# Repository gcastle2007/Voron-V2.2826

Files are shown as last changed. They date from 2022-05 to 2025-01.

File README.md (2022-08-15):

## Configuration of Voron 2.2826

В данном репозитории находится мой актуальный конфиг от 3D принетра Voron 2.4 (V2.2826).

Даный конфиг написан полностью самостоятельно с нуля.
Какие-то дополнительные фичи из макросов были подсмотрены в конфигах нижепредставленных товарищей, разобраны для понимания и перепилены под себя:
- Zellner Alex (очень лютый конфиг, не для слабонервных): https://github.com/zellneralex/klipper_config
- ZZToP: https://github.com/zztopper/voron_v2.4_1030
- Vassssko: https://github.com/Vassssko/voron_v2.4_982

[Раздел макросов ](./MACROS/)

Запуск печати осуществляется через
```
PRINT_START EXTRUDER_TEMP=[first_layer_temperature] BED_TEMP=[first_layer_bed_temperature] CHAMBER=[chamber_temperature] FILAMENT=[filament_type] BMESH=True

Где:
    [first_layer_temperatire] - температура печати первого слоя
    [first_layer_bed_temperature] - температура стола для печати первого слоя
    [chamber_temperature] - минимальная необходима температура камеры для начала печати (сейчас не использую)
    [filament_type] - тип филамента используемого при печати. В зависимости от этого включается Nevermore и вытяжной вентилятор
    BMESH=True - сообщение принтеру, что нужно будет собрать Bed Mesh. Если не нужно, то False

```

## Что существует полезного?

- [Print Tuning Guide](https://github.com/AndrewEllis93/Print-Tuning-Guide)
- [PIF profile](https://github.com/AndrewEllis93/Ellis-PIF-Profile)
- [Exclude Object импортировано в Klipper](https://github.com/Klipper3d/klipper/blob/master/docs/Exclude_Object.md) - [Что для этого нужно?](EXCLUDE.md)

## Полезные, с моей точки зрения, модицифкации:
- [Корзина и щётка для сопла](https://github.com/VoronDesign/VoronUsers/tree/master/abandoned_mods/printer_mods/edwardyeeks/Decontaminator_Purge_Bucket_&_Nozzle_Scrubber)
- [Pinmod, замена винтов на стальные или карбоновые валы, а заодно и шпуль на подшипники](https://github.com/VoronDesign/VoronUsers/tree/master/printer_mods/hartk1213/Voron2.4_Trident_Pins_Mod)
- [Перенос Y-end_stop на A drive](https://github.com/VoronDesign/VoronUsers/tree/master/printer_mods/hartk1213/Voron2.4_Y_Endstop_Relocation)
- [Голова Mantis с отличным обдувом на двух 5015 турбинках](https://github.com/VoronDesign/VoronUsers/tree/master/printer_mods/Long/Mantis_Dual_5015)
- [Dragonator, как обрезать E3DV6, чтобы поставить его в Mantis](imgs/DragonCutting.jpg)
- [Dragonator, шаблон для сверления отверстий в обрезанном E3DV6](STL/Dragonator.stl)
- [Убираем "цепи" (Umbilical Mod)](https://github.com/VoronDesign/VoronUsers/tree/master/printer_mods/Minsekt/Rear_Umbilical)
- [Ретрактор для Umbilical Mod](https://github.com/VoronDesign/VoronUsers/tree/master/printer_mods/Ellis/Badge_Retractor_Mount)
- [Удобные крепления для панелей](https://github.com/Annex-Engineering/Other_Printer_Mods/tree/master/All_Printers/Annex_Panel_2020_Clips_and_Hinges)
- [Установка верхней панели на магнитах (пока сам не тестировал)](https://github.com/VoronDesign/VoronUsers/tree/master/printer_mods/Printopal/Magnetic_top_panel)
- [Vefach, угольный фильтр + Hepa на выдув](https://github.com/VoronDesign/VoronUsers/tree/master/printer_mods/KevinAkaSam/VEFACH)
- [Nevermore, система рециркуляции воздуха в камере. Позволяет быстрее прогреть камеру, а также фильтрует воздух через активированный уголь](https://github.com/nevermore3d/Nevermore_Micro)
- [Klicky Probe](https://github.com/VoronDesign/VoronUsers/tree/master/printer_mods/JosAr/Klicky-Probe)
- [Unklicky, альтернатива Klicky Probe](https://github.com/majarspeed/Unklicky)
- [Кинематическое крепление стола](https://github.com/tanaes/whopping_Voron_mods/tree/main/kinematic_bed)
- [Чем смазывать рельсы?](imgs/SHC007.jpg)

## На что смотреть после Voron 2.4?
- [Voron 0](https://github.com/VoronDesign/Voron-0)
- [Gasherbrum-K3](https://github.com/Annex-Engineering/Gasherbrum-K3)

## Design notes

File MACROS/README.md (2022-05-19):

## Макросы

В данном разделе макросы собраны в группы по выполняемым функциям.

- filament.cfg:
  - FILAMENT_UNLOAD - выгрузка филамента
  - FILAMENT_LOAD - загрузка филамента
  - FILAMENT_CHANGE - смена филамента (не пользуюсь совсем)
  - FILAMENT_BALL - должен делать шарик на конце филамента при выгрузке, но не пользуюсь, т.к. однажды поймал с этим пробку.

- g-codes.cfg - макросы g-code, которыех нет в Klipper:
  - M900 - 
  - M207 - Установка параметров ретракта (втягивание прутка, M207 Snnn Fnnn Znnn – )

- led.cfg - управление освещением внутри принтера. У меня установлена обычная светодиодная лента:
  - LED_OFF - выключить освещение
  - LED_ON - включить освещение на 95%
  - LED_NIGHT - включить ночной режим - 5%

- low_temp_check.cfg
  - LOW_TEMP_CHECK

- nevermore.cfg - управление [Nevermore](https://github.com/nevermore3d/Nevermore_Micro)
  - NEVERMORE_ON - включить Nevermore
  - NEVERMORE_OFF - выключить Nevermore

- prime_line.cfg
  - PRIME_LINE - печатаем полосу филамента перед началом печати, чтобы стабилизировать подачу филамента

- print_start.cfg - скрипт начала печати, о нём будет [отдельная глава](PRINT_START.md)

- print_end.cfg
  - END_OFF_PRINT - скрипт завершающий печать (не учитывает поднялась голова до верха или нет, пока не дописал)

- speed_test.cfg
  - SPEEDTEST - макрос предназначен для проверки максимальой скорости перемещения. Вызывается как SPEEDTEST FMIN=<минимальная скорость> FMAX=<максимальная скорость> STEPS=<кол-во шагов изменения скорости между FMIN и FMAX> CYCLES=<кол-во повторений прогонов на данной скорости>
    - дефолтные параметры, ремендоую изменить на безопасные под свой принтер при первом запуске:
      - FMIN|default(300) - в скобках задаётся минимальная скорость перемещения
      - FMAX|default(700) - в скобках задётся максимальная скорость перемещения
      - STEPS|default(9) - в скобках указано кол-во шагов изменения скорости
      - CYCLES|default(1) - в скобках указано кол-во повторений прогонов на данной скорости

- vefach.cfg
  - VEFACH_ON - включить кулер вефача
  - VEFACH_OFF - выключить кулер вефача

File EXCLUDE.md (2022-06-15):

## Exclude Object

В конфиг Klpper добавляется из https://github.com/Klipper3d/klipper/blob/master/config/sample-macros.cfg:

```
[exclude_object]

[gcode_macro M486]
… <до конца>
```

В SS в PostProcessing добавляем:
```
preprocess_cancellation.py;
```

В SS обязательна галка:

SS_objects

Итого:

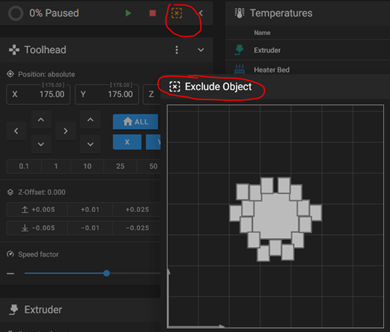
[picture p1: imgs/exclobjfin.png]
Final


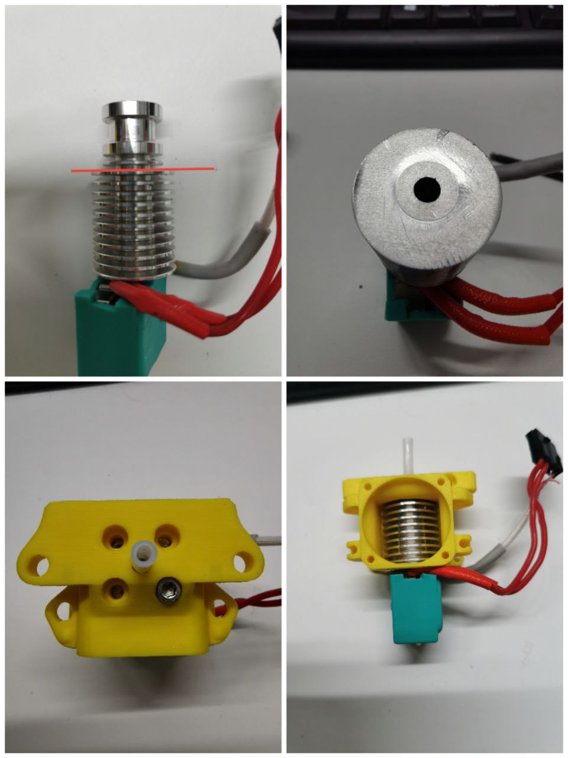
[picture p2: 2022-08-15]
imgs/DragonCutting.jpg

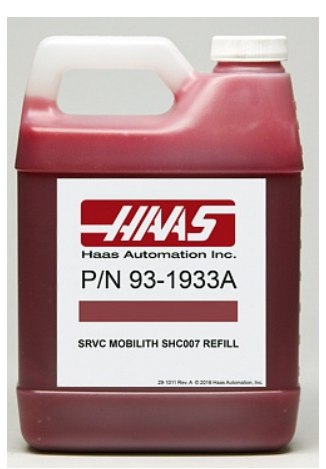
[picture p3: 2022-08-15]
imgs/SHC007.jpg

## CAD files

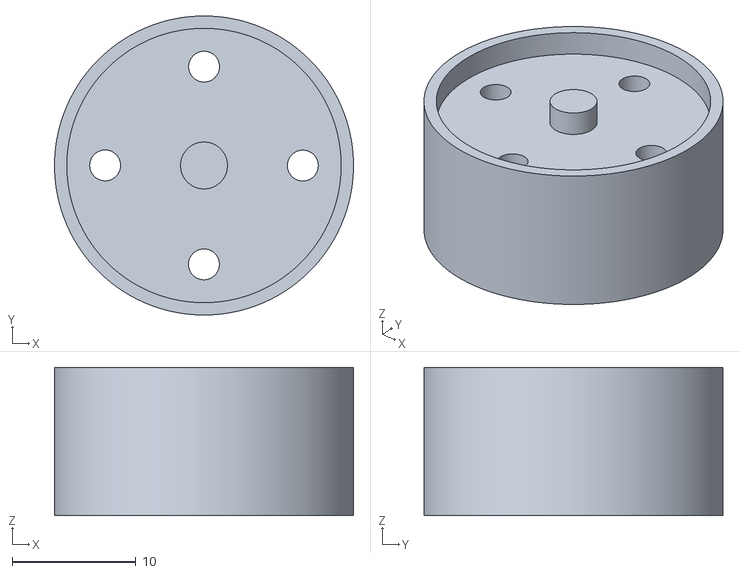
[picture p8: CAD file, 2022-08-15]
STL/Dragonator.stl
24.2 x 24.2 x 12.0

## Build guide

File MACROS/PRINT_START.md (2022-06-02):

## Макрос PRINT_START

Идеология данного макроса заключается в том, чтобы разбить процесс подготовки печати на этапы, нагреть стол, убедиться, что средний PID стола стал ниже 25% (а это значит, что стол прогрелся):
- Prepare - самая первая стадия. До этого идёт задание параметров для необходимых переменных.
- Heating bed - стадия запуска прогрева стола. Также запускается предварительный нагрев экструдера.
- HeatSoak - стадия догрева стола. В данном макросе применена идеология того, что когда стол прогревается, то средняя величина PID прогрева стола уменьшается. В моём случае ждём, когда PID станет 25%, после этого можно переходить на следующую стадию.
- QGL - делаем Quad Gantry Level для гантри.
- BedMesh - в засимости от необходимости, либо перестраиваем полностью Bed Mesh, либо подгружаем уже заранее сохранённую карту в зависимости от температуры.
- Final - последняя стадия, в которой догревается экструдер, чистится сопло, калибркуется Z-Offset через CALIBRATE_Z, прогоняется PRIME_LINE и далее уже идёт печать.

Скрипт периодически может корректироваться и меняться, в зависимости от моих потребностей.

Запуск печати осуществляется:
PRINT_START EXTRUDER_TEMP=[first_layer_temperature] BED_TEMP=[first_layer_bed_temperature] CHAMBER=[chamber_temperature] FILAMENT=[filament_type] BMESH=True
* [first_layer_temperatire] - температура печати первого слоя
* [first_layer_bed_temperature] - температура стола для печати первого слоя
* [chamber_temperature] - минимальная необходима температура камеры для начала печати (сейчас не использую)
* [filament_type] - тип филамента используемого при печати. В зависимости от этого включается Nevermore и вытяжной вентилятор
* BMESH=True - сообщение принтеру, что нужно будет собрать Bed Mesh. Если не нужно, то False

### Разберём подробно все этапы и действия.

```
[gcode_macro PRINT_START]
```
### Инициализация необходимых переменных при запуске Klipper:
```
variable_retract: 0                   # задание ретракта
##  User Paramaters
##  BED_TEMP      : Target temperature for the Bed. Is also used to decide 
##                  if heatsoak is needed
##  EXTRUDER_TEMP : Target temperature for the Extruder
##  RETRACT_LEN   : Retract length for firmware retracts
##  RETRACT_SPD   : Retract speed for firmware retracts
##  System Varables
# change this to define the wait time per call
variable_extruder: 245                # температура экструдера по умолчанию
variable_extruder_pre: 171            # температура преднагрева экструдера по умолчанию
variable_bed: 100                     # температура стола по умолчанию
variable_print_info: 'true'
## Valid state 
##   Prepare : decision if heat Soak is needed 
##   HeatSoak: loop the time specified with SOAK
##   Final   : all what needs to be done after wait timet
variable_state: 'Prepare'             # переменная state - задаёт этап выполнения подготовки к печати. По умолчанию стадия Prepare
variable_first: 'true'
variable_soak: 0.35                   # ожидаемое значание среднеро PWM стола. Идея состоит в том, чтобы снять некоторое кол-во показаний PWM и высчитать среднее.
variable_pwm: 1                       # начальное значение PWM
variable_avgpwm: 1                    # среднее накопительное значение PWM
variable_tests: 0                     # счётчик опросов PWM
variable_left: 30                     # кол-во опросов PWM. Опросы будут проводиться 1 раз в секунду. Соответственно 30 раз.
variable_clean2: False
variable_bmeshv: False                # перепенная, отвечающая за необходимость выполнения BED_MESH_CALIBRATE (True/False)
gcode:
  {% set extruder_temp = params.EXTRUDER_TEMP|default(240)|float %}   # Получание значения температуры экструдера из слайсера
  {% set bed_temp = params.BED_TEMP|default(80)|float %}              # Получание значения температуры стола из слайсера
  {% set E = printer["gcode_macro PRINT_START"].retract|float %}      # Retract - variable from this macros
#  {% set soak = params.SOAK|default(0.25) %}                         # 
  {% set soak = printer["gcode_macro PRINT_START"].soak %}            # Значение ожидаемого PID
  {% set actPwm = printer.heater_bed.power|float %}                   # Получение актуального PWD для стола
  {% set cham_temp = params.CHAMBER|default(40)|float %}              # температура нагрева камеры. В настоящее время мной не используется
  {% set filament_name = params.FILAMENT%}                            # поределение типа филамента из слайсера. исходя из этого я запускаю Nevermore или нет
  {% set bmesh = params.BMESH|default("no") %}                        # Нужно ли собирать новый bed mesh, yes/no задаётся через слайсер

#############  BED temp values  #############
  # get actual temp from extra sensor or heater sensor / получение актуальной температуры стола с дополнительного сенсора или с термистора в столе
  {% if 'temperature_sensor bed' in printer %}                             # проверка на наличие дополнительного сенсора
    {% set actBed = printer['temperature_sensor bed'].temperature|int %}   # если дополнительный сенсор есть, то actBed (актуальная температура стола) равен данным с температуры этого сенсора
  {% else %}
    {% set actBed = printer.heater_bed.temperature|int %}                  # иначе actBed равна температуры с термистора стола по умолчанию
  {% endif %}
  # get max allow bed temp from config. Lower it by 5C to avoid shutdown
  {% set cfg_bed_max = printer.configfile.settings.heater_bed.max_temp|int - 5 %} # получение максимальной температуры стола, которую можно использовать. Это максимальная температура, указанная в конфиге минус 5 градусов.
```

### Подготовительная стадия, называется Prepare:
```
#############  Prepare Stage #############
  {% if state == 'Prepare' %}  
#    _PRINT_AR T="Preparation stage"
    M117 Preparation stage
    {% set bed_temp = params.BED_TEMP|default(80)|int %}
    {% set extruder_temp = params.EXTRUDER_TEMP|default(240)|int %}
    {% set extruder_temp_pre = (extruder_temp|float * 0.7)|int %}
#    {% set soak = params.SOAK|default(0.35) %}
  {% set soak = printer["gcode_macro PRINT_START"].soak %}  
```

### Стадия сохранения значений глобальных переменных:
```
#############  Variable setup  #############
    CLEAR_PAUSE
    SET_GCODE_VARIABLE MACRO=CANCEL_PRINT VARIABLE=execute VALUE='"false"'                # macros CANCEL_PRINT must have variable "execute" with value "false"
    SET_GCODE_VARIABLE MACRO=PRINT_START VARIABLE=extruder VALUE={extruder_temp}          # extruder temperature
    SET_GCODE_VARIABLE MACRO=PRINT_START VARIABLE=extruder_pre VALUE={extruder_temp_pre}  # extruder pre-heat
    SET_GCODE_VARIABLE MACRO=PRINT_START VARIABLE=bed VALUE={bed_temp}                    # target bed temperature
    SET_GCODE_VARIABLE MACRO=PRINT_START VARIABLE=bmeshv VALUE={bmesh}                    # bed mesh new or not new
    SET_GCODE_VARIABLE MACRO=PRINT_START VARIABLE=left VALUE=30                           # counter for PWM calculate
```

### Стадия нагрева стола:
```
#############  Heating bed  #############
    LED_ON                                                                       # включение освещения внутри принтера
    # start Nevermore if ABS
    {% if "ABS" in filament_name %}                                              # если печатается SBD, то включается Nevermore, чтобы фильтровать воздух в режиме рециркуляции внутри камеры
    #      NEVERMORE_ON
       SET_FAN_SPEED FAN=Nevermore SPEED=0.95
    {% else %}
      NEVERMORE_OFF                                                              # иначе не включается
    {% endif %}
    _PRINT_AR T="Heating Bed"                                                    # выводим сообщение от стади на грева стола
    {action_respond_info("Heating Bed")}
    M140 S{bed_temp|int}                                                         # запускаем нагрев стола и не ждём
    M104 S{extruder_pre|int}  ; heat bed and wait                                # запускаем преднагрев экструдера и ждём
    G28                                                                          # хомимся
    G90                                                                          # координаты абсолютные
    G0 Z30 F1500                                                                 # поднимем голову на 30мм
    G0 X175 Y175 F24000                                                          # переместим её в центр стола
    M106 S90              ; switch part cooling ~35% to move air in chamber      # включим, примерно, на 35% фаны охлаждения модели, чтобы перепешивать воздух в камере
    M190 S{bed_temp|int}  ; heat bed and wait                                    # нагреваем стол, но уже ждём
    PAUSE_BASE                                                                   # PAUSE!!!! важный момент, если этого не сделать, то получим начало печати раньше времени
    {% set pwm = printer['heater_bed'].power | float %}                          # получаем PWM от нагревателя стола
    SET_GCODE_VARIABLE MACRO=PRINT_START VARIABLE=pwm VALUE={pwm}                # сохраняем глобально значения переменных
    SET_GCODE_VARIABLE MACRO=PRINT_START VARIABLE=avgpwm VALUE={pwm}             # ...
    SET_GCODE_VARIABLE MACRO=PRINT_START VARIABLE=tests VALUE=1                  # ...
    _PRINT_AR T="{"T:%02d/30 P:%.3f/%.3f" % (left|int,pwm|float,soak|float)}"    # выводим сообщение
    # Call the wait macro the first time
    SET_GCODE_VARIABLE MACRO=PRINT_START VARIABLE=state VALUE='"HeatSoak"'       # устанавливаем стадию догрева стола - HeatSoak
    UPDATE_DELAYED_GCODE ID=START_PRINT_WAIT DURATION=0.1                        # вывваем скрипт START_PRINT_WAIT на выполнение, но с задержкой старта с 0.1 секунды
```

### Стадия догрева стола до PID = 35%:
```
#############  HeatSoak #############
  {% elif state == 'HeatSoak' %}
    M117 HeatSoak                                                                # Вывод на экран сообщения о догреве стола
    {action_respond_info("HeatSoak")}
    {% if left == 0 %}
      {% if avgpwm >= soak|float %}
        SET_GCODE_VARIABLE MACRO=PRINT_START VARIABLE=pwm VALUE=0                # сброс значения PWM в ноль
        SET_GCODE_VARIABLE MACRO=PRINT_START VARIABLE=tests VALUE=0              # сброс счётчика тестовых запросов в ноль
        SET_GCODE_VARIABLE MACRO=PRINT_START VARIABLE=left VALUE=30              # кол-во опросов ставим 30. Ставятся с задержкой 30 секунд.
      {% else %}
        {action_respond_info("Done. Mean PWM: %f" % (avgpwm|float))}
        SET_GCODE_VARIABLE MACRO=PRINT_START VARIABLE=state VALUE='"QGL"'        # Переходим на стадию Quad Gantry Level (выравнивание портала)
        {action_respond_info("Must made Bed Mesh")}
      {% endif %}
    {% endif %}
    UPDATE_DELAYED_GCODE ID=START_PRINT_WAIT DURATION=1
```

### Стадия выравнивания портала:
```
#############  QGL #############
  {% elif state == 'QGL' %}
    M106 S0                                                                      # выключаем вентиляторы обдува модели
    M117 Quad Gantry Level                                                       # сообщение на экран
    QUAD_GANTRY_LEVEL                                                            # выравниваем портал
    G28 Z                                                                        # хомим снова Z, т.к. если у нас портал был искривлён, то предыдущий хоминг не корректен
    SET_GCODE_VARIABLE MACRO=PRINT_START VARIABLE=state VALUE='"BedMesh"'        # переводим стадию на сборку Bed Mesh
    UPDATE_DELAYED_GCODE ID=START_PRINT_WAIT DURATION=0.1
```

### Стадия калибровки меша (BED_MESH_CALIBRATE):
```
#############  Bed Mesh calibrate #############
  {% elif state == 'BedMesh' %}
    _PRINT_AR T="Bed mesh stage"
    {action_respond_info("Bed Mesh Calibrate")}
    {% if bmeshv %}
      {action_respond_info("New bed mesh create")}
      _PRINT_AR T="New bed mesh create"
      BED_MESH_CALIBRATE
    {% else %}
      {% if bed_temp>=110 %}
        BED_MESH_PROFILE LOAD=PEI-110T
      {% endif %}
      {% if bed_temp>=100 and bed_temp<110 %}
        BED_MESH_PROFILE LOAD=PEI-100T
      {% endif %}
      {% if bed_temp>=90 and bed_temp<100 %}
        BED_MESH_PROFILE LOAD=PEI-90T
      {% endif %}
      {% if bed_temp>=80 and bed_temp<90 %}
        BED_MESH_PROFILE LOAD=PEI-80T
      {% endif %}
      {% if bed_temp>=70 and bed_temp<80 %}
        BED_MESH_PROFILE LOAD=PEI-70T
      {% endif %}
      {% if bed_temp>=60 and bed_temp<70 %}
        BED_MESH_PROFILE LOAD=PEI-60T
      {% endif %}
    {% endif %}
    G90
    G0 Z30 F1500                                                                 # Z to low 30
    G1 X175 Y175 F30000                                                            # head to center of bed
    SET_GCODE_VARIABLE MACRO=PRINT_START VARIABLE=state VALUE='"Final"'
    UPDATE_DELAYED_GCODE ID=START_PRINT_WAIT DURATION=0.1
```

### Финальная стадия:
```
#############  Final Stage #############
  {% elif state == 'Final' %}
    {action_respond_info("Final Stage")}
    M117 Final Stage
    # set staus back to prepare for the next run 
    SET_GCODE_VARIABLE MACRO=PRINT_START VARIABLE=state VALUE='"Prepare"'       # Восстанавливаем будущий статус на Prepare для следущей печати
    M109 S{extruder|int} ; heat extruder and wait                               # догреваем экструдер и ждём
    M117 Clean nozzle.                                                          # сообщение об очистке сопла на экран
    CLEAN_NOZZLE                                                                # едем чистить сопло
    M83                                                                         # перевод мотора экструдера в режим относительных координат
    G1 E-2                                                                      # детаем откат филамента на 2мм, чтобы сопло не текло
    M117 Caibration Z-offset.                                                   # сообщение о калибровке Z-offset на экран
    RESUME_BASE                                                                 # Важно! Просыпаемся от PAUSE, чтобы значения калибровки запомнились
    CALIBRATE_Z                                                                 # Калибруем Z-offset
    PAUSE_BASE                                                                  # Важно! Снова уходим в PAUSE
    G92 E0                                                                      # Сброс значеня экструдера в ноль
    M117 Prime Line Print                                                       # сообщение о печати Prime Line
    PRIME_LINE                                                                  # Печатаем Prime Line
    M117                                                                        # Очищаем экран
    RESUME_BASE                                                                 # Просыпаемся из паузы и... уходим в печать
  {% endif %}
#############  Begin of ptinting #############
```

### Скрипт PRINT_START_WAIT - запускается на выполнение с задержкой. Также позволяет просчитать средний PWM на базе выборки из N значений.
```
[delayed_gcode START_PRINT_WAIT]
gcode:
 # Print remaining time
  {% if printer["gcode_macro PRINT_START"].state == 'HeatSoak' %}
      {% set pwm = printer['heater_bed'].power | float %}
      {% set totalpwm = printer["gcode_macro PRINT_START"].pwm|float %}
      {% set tests = printer["gcode_macro PRINT_START"].tests|int + 1 %}
      {% set left = printer["gcode_macro PRINT_START"].left|int - 1 %}
      {% set soak = printer["gcode_macro PRINT_START"].soak | float %}
      {% set avgpwm = ((totalpwm+pwm)/tests)|float %}
      SET_GCODE_VARIABLE MACRO=PRINT_START VARIABLE=avgpwm VALUE={avgpwm}
      SET_GCODE_VARIABLE MACRO=PRINT_START VARIABLE=pwm VALUE={(totalpwm+pwm)|float}
      SET_GCODE_VARIABLE MACRO=PRINT_START VARIABLE=tests VALUE={tests}
      SET_GCODE_VARIABLE MACRO=PRINT_START VARIABLE=left VALUE={left}
      M117 S{'T:%02d' % left|int}{'/30 P:%.2f' % (avgpwm|float)}{'/%.2f' % (soak|float)}
  {% endif %}
  # Check CANCLE_PRINT was executed
  {% if printer["gcode_macro CANCEL_PRINT"].execute == 'false' %}
    # Jump back to PRINT_START
    PRINT_START
  {% else %}
    # break loop
    # insure state is correct for the next print start
    SET_GCODE_VARIABLE MACRO=CANCEL_PRINT VARIABLE=execute VALUE='"false"'
    SET_GCODE_VARIABLE MACRO=PRINT_START VARIABLE=state VALUE='"Prepare"'
#    UPDATE_DELAYED_GCODE ID=_CLEAR_DISPLAY DURATION=1
  {% endif %}
```

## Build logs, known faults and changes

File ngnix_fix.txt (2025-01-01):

ngnix.conf

add to end of config section:
proxy_read_timeout 300;
proxy_connect_timeout 300;
proxy_send_timeout 300;

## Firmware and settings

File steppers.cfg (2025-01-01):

[stepper_x]
step_pin: PG0
dir_pin: !PG1
enable_pin: !PF15
microsteps: 32
rotation_distance: 40
full_steps_per_rotation:200
endstop_pin: PG6
;position_endstop: 0
position_endstop: 350
position_max: 352
position_min: 0
homing_speed: 150
homing_retract_dist: 5.0
second_homing_speed: 5

[tmc2209 stepper_x]
uart_pin: PD11
interpolate: False
run_current: 1.3
;hold_current: 0.875
sense_resistor: 0.110
;stealthchop_threshold: 0
driver_TBL: 2
driver_TOFF: 4
driver_HEND: 3
driver_HSTRT: 0

# [tmc5160 stepper_x]
# cs_pin: PD11
# #spi_bus: spi1
# interpolate: False
# #run_current: 1.2
# run_current: 0.95
# spi_software_sclk_pin: SCK
# spi_software_mosi_pin: MOSI
# spi_software_miso_pin: MISO
# stealthchop_threshold: 0
# sense_resistor: 0.075
# driver_TPFD: 0
# driver_TBL: 2
# driver_TOFF: 3
# driver_HEND: 5
# driver_HSTRT: 7

[stepper_y]
step_pin: PF13
dir_pin: PF12
enable_pin: !PF14
microsteps: 32
rotation_distance: 40
full_steps_per_rotation:200
endstop_pin: PG9
position_endstop: 360
;position_endstop: -10
position_max: 362
position_min: 0
homing_speed: 150
homing_retract_dist: 5.0
second_homing_speed: 5
#endstop_pin: tmc2209_stepper_y:virtual_endstop ; for sensorless homing

[tmc2209 stepper_y]
uart_pin: PC4
interpolate: False
run_current: 1.3
;hold_current: 0.875
sense_resistor: 0.110
;stealthchop_threshold: 0
driver_TBL: 2
driver_TOFF: 4
driver_HEND: 3
driver_HSTRT: 0
; it is for sensorless homing
;diag_pin: PG9 ; for sensorless homing
;driver_SGTHRS: 100

# [tmc5160 stepper_y]
# cs_pin: PC4
# #spi_bus: spi1
# interpolate: False
# #run_current: 1.2
# run_current: 0.95
# spi_software_sclk_pin: SCK
# spi_software_mosi_pin: MOSI
# spi_software_miso_pin: MISO
# stealthchop_threshold: 0
# sense_resistor: 0.075
# driver_TPFD: 0
# driver_TBL: 2
# driver_TOFF: 3
# driver_HEND: 5
# driver_HSTRT: 7

[stepper_z]
dir_pin: !PG3
step_pin: PF11
enable_pin: !PG5
microsteps: 32
rotation_distance: 40
gear_ratio: 80:16
endstop_pin: probe:z_virtual_endstop
#endstop_pin: PG10
#position_endstop: 0
#position_endstop: 0.507
#position_endstop: 0.510
position_max: 320
position_min: -5
homing_speed: 15.0
second_homing_speed: 3.0
homing_retract_dist: 2.0

[tmc2209 stepper_z]
uart_pin: PC6
interpolate: False
run_current: 0.7
#hold_current: 1.1
sense_resistor: 0.110
stealthchop_threshold: 0
driver_TBL: 2
driver_TOFF: 4
driver_HEND: 3
driver_HSTRT: 2

[stepper_z1]
dir_pin: PC1
step_pin: PG4
enable_pin: !PA0
microsteps: 32
rotation_distance: 40
gear_ratio: 80:16

[tmc2209 stepper_z1]
uart_pin: PC7
interpolate: False
run_current: 0.8
#hold_current: 1.1
sense_resistor: 0.110
stealthchop_threshold: 0
driver_TBL: 2
driver_TOFF: 4
driver_HEND: 3
driver_HSTRT: 2

[stepper_z2]
dir_pin: !PF10
step_pin: PF9
enable_pin: !PG2
microsteps: 32
rotation_distance: 40
gear_ratio: 80:16

[tmc2209 stepper_z2]
uart_pin: PF2
interpolate: False
run_current: 0.8
#hold_current: 1.1
sense_resistor: 0.110
stealthchop_threshold: 0
driver_TBL: 2
driver_TOFF: 4
driver_HEND: 3
driver_HSTRT: 2

[stepper_z3]
dir_pin: PF0
step_pin: PC13
enable_pin: !PF1
microsteps: 32
rotation_distance: 40
gear_ratio: 80:16

[tmc2209 stepper_z3]
uart_pin: PE4
interpolate: False
run_current: 0.8
#hold_current: 1.1
sense_resistor: 0.110
stealthchop_threshold: 0
driver_TBL: 2
driver_TOFF: 4
driver_HEND: 3
driver_HSTRT: 2

##	E0 on MCU X/Y
##	Make sure to update below for your relevant driver (2208 or 2209)
;[tmc2209 extruder]
############### Different Clockworks Setups ###############
##  Afterburner: Stepper Motor 0.9 step distance 0.00120 calibrated 0.001196
##  run_current: 0.6
##  hold_current: 0.6
############################################################
##  Galileo: Stepper Motor 1.8 step distance 0.00132 calibrated 0,001320975
##  run_current: 0.25
##  hold_current: 0.20
############### Different Clockworks Setups ###############
;uart_pin: PE1
;interpolate: false
;run_current: 0.35
;hold_current: 0.2
;sense_resistor: 0.110
;stealthchop_threshold: 0

[delayed_gcode disable_multistep_filt]
initial_duration: 0.5
gcode:
  SET_TMC_FIELD STEPPER=stepper_x FIELD=multistep_filt VALUE=0
  SET_TMC_FIELD STEPPER=stepper_y FIELD=multistep_filt VALUE=0
  SET_TMC_FIELD STEPPER=stepper_z FIELD=multistep_filt VALUE=0
  SET_TMC_FIELD STEPPER=stepper_z1 FIELD=multistep_filt VALUE=0
  SET_TMC_FIELD STEPPER=stepper_z2 FIELD=multistep_filt VALUE=0
  SET_TMC_FIELD STEPPER=stepper_z3 FIELD=multistep_filt VALUE=0
  SET_TMC_FIELD STEPPER=extruder FIELD=multistep_filt VALUE=0

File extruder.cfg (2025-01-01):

[extruder]
step_pin: PE2
dir_pin: !PE3
enable_pin: !PD4
microsteps: 16

# SBurner
#rotation_distance = 22.10874179 
#gear_ratio = 50:17

# Mantis
rotation_distance = 23.1654
gear_ratio = 50:10

full_steps_per_rotation: 200
;nozzle_diameter: 0.400
nozzle_diameter: 0.600
;nozzle_diameter: 0.500
;nozzle_diameter: 0.400
filament_diameter: 1.750
heater_pin: PA2
;pressure_advance_smooth_time: 0.002

#=========== ATC Semitec 104GT-2 Thermal Config ===========
# sensor_type: ATC Semitec 104GT-2   # Volcano
sensor_type: ATC Semitec 104NT-4-R025H42G   # CHC Pro
sensor_pin: PF7
smooth_time: 0.4

#[include thermistor_pt100.cfg]
#[include thermistor_ATC-Semitec-104GT-2.cfg]

#=========== PT100 Thermal Config ===========
;sensor_type: MAX31865
# One of "MAX6675", "MAX31855", "MAX31856", or "MAX31865".
;spi_speed: 4000000
# The SPI speed (in hz) to use when communicating with the chip.
# The default is 4000000.
#spi_bus:
;spi_software_sclk_pin: EXP2_2
;spi_software_mosi_pin: EXP2_6
;spi_software_miso_pin: EXP2_1
;sensor_pin: PD3 # The chip select line for the sensor chip. This parameter must be provided.
#tc_type: K
#tc_use_50Hz_filter: False
#tc_averaging_count: 1
# The above parameters control the sensor parameters of MAX31856
# chips. The defaults for each parameter are next to the parameter
# name in the above list.
;rtd_nominal_r: 100
#rtd_nominal_r: 110
;rtd_reference_r: 402
#rtd_reference_r: 430
#rtd_reference_r: 473
;rtd_num_of_wires: 2
;rtd_use_50Hz_filter: True
# The above parameters control the sensor parameters of MAX31865
# chips. The defaults for each parameter are next to the parameter
# name in the above list.

min_temp: 0
max_temp: 300
#min_extrude_temp: 190
min_extrude_temp: 5
max_extrude_only_distance: 400.0
max_extrude_cross_section: 500.0
max_extrude_only_velocity: 50

;control = pid

# Dragon SBurner
#pid_Kp=17.431
#pid_Ki=0.945
#pid_Kd=80.400

# E3d V6 PA_FG6
#pid_Kp=26.373
#pid_Ki=1.503
#pid_Kd=115.713

#Volcano
#pid_Kp=33.466
#pid_Ki=1.703
#pid_Kd=164.401

# Dragon on Mantis
;pid_Kp: 18.117
;pid_Ki: 0.982
;pid_Kd: 83.566

# Dragon on Mantis with 104GT-2
#pid_Kp=22.411
#pid_Ki=1.525
#pid_Kd=82.362

# Volcano on Mantis with 104GT-2
#pid_Kp=21.616
#pid_Ki=1.201
#pid_Kd=97.272

# CHC Pro on Mantis with 104NT-2
;pid_Kp=20.450
;pid_Ki=1.920
;pid_Kd=54.447

;pid_Kp=18.620
;pid_Ki=1.633
;pid_Kd=53.066

#Volcano on Mantis
#pid_Kp=32.612
#pid_Ki=1.421
#pid_Kd=187.113



[tmc2209 extruder]
uart_pin: PE1
interpolate: False
run_current: 0.35
;hold_current: 0.2
sense_resistor: 0.110
stealthchop_threshold: 200
;driver_TBL: 0
;driver_TOFF: 7
;driver_HEND: 2
;driver_HSTRT: 0
;driver_PWM_GRAD: 8
;driver_PWM_LIM: 10

[verify_heater extruder]
max_error: 1200
#   The maximum "cumulative temperature error" before raising an
#   error. Smaller values result in stricter checking and larger
#   values allow for more time before an error is reported.
#   Specifically, the temperature is inspected once a second and if it
#   is close to the target temperature then an internal "error
#   counter" is reset; otherwise, if the temperature is below the
#   target range then the counter is increased by the amount the
#   reported temperature differs from that range. Should the counter
#   exceed this "max_error" then an error is raised. The default is
#   120.
#check_gain_time: 20
#   This controls heater verification during initial heating. Smaller
#   values result in stricter checking and larger values allow for
#   more time before an error is reported. Specifically, during
#   initial heating, as long as the heater increases in temperature
#   within this time frame (specified in seconds) then the internal
#   "error counter" is reset. The default is 20 seconds for extruders
#   and 60 seconds for heater_bed.
#hysteresis: 5
#   The maximum temperature difference (in Celsius) to a target
#   temperature that is considered in range of the target. This
#   controls the max_error range check. It is rare to customize this
#   value. The default is 5.
#heating_gain: 2
#   The minimum temperature (in Celsius) that the heater must increase
#   by during the check_gain_time check. It is rare to customize this
#   value. The default is 2.

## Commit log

2022-05-19 фввщт
2022-05-19 fix print_start macros
    [prime_line.cfg, print_start.cfg]
2022-05-19 добавить полезного
2022-05-19 print start description
2022-05-24 Fix error in BadMash calibration execution.
    [print_start.cfg]
2022-05-24 readme print_start update
    [print_start.cfg]
2022-05-31 update after cable recover
    [extruder.cfg, klicky-probe.cfg, print_start.cfg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]
2022-06-08 update PID calibrate for Mantis
    [extruder.cfg, fans.cfg, filament_runout_detection.cfg]
2022-06-15 add Exclude Obect
    [exclude.cfg, print_end.cfg, printer.cfg]
2022-07-27 set unklicky Z-end-stop in new position
    [klicky-probe.cfg, steppers.cfg, z_calibration.cfg]
2022-08-08 bed mesh 7x7
    [bed_mesh.cfg, klicky-probe.cfg, probe.cfg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]
2022-08-28 Fix errors and move to 48V on A/B drive.
    [idle_timeout.cfg, printer.cfg, speed_test.cfg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]
2025-01-01 update 2025_01_01
    [bed_mesh.cfg, bedfans.cfg, extruder.cfg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]
